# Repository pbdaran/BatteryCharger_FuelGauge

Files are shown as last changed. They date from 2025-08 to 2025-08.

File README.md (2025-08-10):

# Breakout Board: Battery Charger & Fuel Gauge — Design Story and Choices

Designing a compact, reliable battery management breakout board isn’t just about cramming chips together — it’s about understanding the trade-offs behind every component choice.  
Here’s the thinking behind the **Battery Charger & Fuel Gauge Breakout Board** and why I chose the ICs I did.

## 1. The Battery Charger: BQ24040 vs. TP4056

The **TP4056** has earned its fame in the maker world — it’s cheap, easy to use, and well supported. But it hides a quirk that can cause headaches in certain designs.

**The TP4056 quirk:**
- Pre-charge threshold: ~3.0 V
- Fixed pre-charge (trickle charge) current: **10 mA**
- If your battery is below 3 V and you have an **LDO** pulling ~10 mA from the charger output (to power 3.3 V logic, for instance), the TP4056 will happily supply that current to the LDO… **and zero to the battery**.
- Result? The battery never rises above 3 V, and the charger never switches to constant current mode. Stalemate.

**How the BQ24040 solves it:**
- **Lower pre-charge threshold**: ~2.5 V (battery starts charging earlier in its discharge)
- **Configurable pre-charge current**: e.g., 50 mA — plenty to both feed your LDO and still trickle energy into the cell.
- Additional perks:
  - Power path management: can supply load and charge battery simultaneously.
  - Status outputs for charge and fault indication.
  - Thermal regulation built in.

This means your system boots faster from a dead battery, and you don’t get stuck in a “never charging” deadlock.

## 2. The Fuel Gauge: BQ27621-G1 and the Calibration Dilemma

Battery fuel gauging is trickier than it looks. You can measure voltage, but it doesn’t tell the whole story about state of charge (SoC).

**Two main approaches:**
1. **Impedance Tracking** — Highly accurate, but requires painful calibration and “training” cycles to match the gauge to your specific cell.  
   Great for high-volume products, less great for quick prototypes or small-run boards.
2. **Voltage Correlation** — Uses cell voltage, temperature, and discharge patterns to estimate SoC. Less accurate over extreme conditions, but easy to set up.

The **BQ27621-G1** uses a **dynamic voltage correlation algorithm**:
- No complex calibration process.
- Good enough accuracy for most portable projects.
- Very low quiescent current — ideal for battery-powered devices.
- I²C interface for easy microcontroller integration.

For a breakout board aimed at prototyping and flexibility, avoiding impedance tracking’s long setup time is worth the small trade-off in accuracy.

## 3. Board Connections and Options

This board isn’t just two chips and some passives — it’s designed to be **flexible** in different setups.

**Key features:**
- **USB input** for charging.
- **Battery JST connector** for Li-Ion/Li-Po cells.
- **Load output** that stays powered even while charging (thanks to the BQ24040’s power path management).
- **I²C interface** (SDA, SCL) for reading fuel gauge data.
- **Configurable pre-charge current** via resistor selection.
- **Charge status pins** for LED indicators or MCU monitoring.

## 4. Why This Combo Works Well

The **BQ24040 + BQ27621-G1** pairing offers:
- Robust charging under low-voltage conditions.
- Accurate-enough battery state reporting without lengthy setup.
- Support for both charging and powering your project at the same time.
- Minimal parts count without sacrificing essential battery management features.

_Refer to the Design Document for the board configurations_

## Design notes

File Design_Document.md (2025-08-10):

# Hardware Design Document: BatteryCharger_FuelGauge_Breakout_Board

## 1. Overview

This breakout board provides battery charging and fuel gauging for single-cell Li-Ion batteries. It integrates the Texas Instruments BQ24040 battery charger and the BQ27621-G1 fuel gauge IC. The design supports USB-C input and configurable logic levels for host communication.

## 2. Major Components

### 2.1 Battery Charger IC (TI BQ24040)
- **Package:** WSON-10-1EP (2x2mm)
- **Functions:** Li-Ion single-cell battery charging, integrated power path management.
- **Key Pins:**
    - IN: Power input (VBUS from USB-C)
    - OUT: Charger output to battery and system
    - ISET/ISET2: Charge and input current setting (resistor configurable)
    - TS: Battery temperature sensing
    - PRETERM: Precharge current setting
    - ~CHG, ~PG: Charge and power-good status outputs
- **Thermal Pad (EPAD):** Must be connected to ground.

### 2.2 Fuel Gauge IC (TI BQ27621-G1)
- **Package:** DSBGA-9 (1.62x1.58mm)
- **Functions:** Battery fuel gauging via Impedance Track™.
- **Key Pins:**
    - BAT: Battery voltage sense
    - VDD: Power supply (1.8V internal, or external VDD)
    - SCL/SDA: I2C clock/data for host communication
    - GPOUT: Programmable output (status/interrupt)
    - BIN: Optional battery thermistor input (configurable via jumper)
    - NC: No connect

### 2.3 USB-C Input Connector
- **Type:** USB_C_Receptacle_USB2.0_16P
- **Pins:** VBUS, GND, CC1/CC2, SBU1/SBU2, D+/D- for USB 2.0 only.

### 2.4 Connectors
- **J1:** 5-pin host interface (VDDE, GPOUT, SCL, SDA, GND)
- **J2:** 3-pin battery connector (+BATT, BIN, GND)
- **J4:** 3-pin auxiliary connector

### 2.5 Passive Components
- **Resistors:** Current setting, pull-ups, configuration (e.g., 10k, 5.1k, 1.8M, 2k, 1k)
- **Capacitors:** Decoupling and filtering (e.g., 0.1uF, 1uF, 0.47uF)
- **TVS Diode:** USB port protection (SMBJ7.5CA)

### 2.6 Jumpers
- **JP1 (BIN select):** Selects battery temperature sensing mode (default disables BIN, option for thermistor).
- **JP2 (VDD select):** Selects power source for fuel gauge I/O (default external 3.3V, option for internal 1.8V).

## 3. Configuration Options

| Jumper | Default | Alternate | Description |
|---|---|---|---|
| JP1(1-2) | Pulled down through 10k; BIN disabled | JP1(2-3): Pulled up through 1.8M; battery pack must have thermistor | BIN configuration |
| JP2(1-2) | Connect external 3.3V on VDDE pin | JP2(2-3): Use 1.8V regulator output | VDD configuration for I2C interface |

## 4. Interfaces

### 4.1 Host Interface (J1)
| Pin | Signal | Description |
|-----|---|---|
| 1 | VDDE | Connect 3.3V (logic level) |
| 2 | GPOUT | Programmable output |
| 3 | SCL | I2C clock |
| 4 | SDA | I2C data |
| 5 | GND | Ground |

### 4.2 Battery Connector (J2)
| Pin | Signal | Description |
|-----|---|---|
| 1 | +BATT | Battery positive terminal |
| 2 | BIN | Battery NTC/thermistor |
| 3 | GND | Battery ground |

## 5. Power Domains

- **VBUS (USB):** Main input power for charging.
- **VDDE:** External I/O voltage (3.3V or 1.8V via JP2).
- **VDD:** Fuel gauge IC supply, from internal regulator or external VDDE.
- **GND:** System ground.

## 6. Notes & Recommendations

- By default, the BIN pin function is disabled. If your battery pack has an internal NTC, set JP1 to 2-3.
- By default, use external VDD of 3.3V on J1 pin 1. If your interface logic is 1.8V, set JP2 to 2-3 to use the fuel gauge's internal 1.8V regulator.
- TVS diode protects USB data lines.
- Mounting holes and fiducials are provided for PCB assembly.

## 7. Reference Designators

- **U1:** Fuel Gauge (BQ27621-G1)
- **U2:** Charger (BQ24040)
- **J1, J2, J3, J4:** Connectors
- **JP1, JP2:** Configuration jumpers
- **R1-R14, C1-C5, D1:** Passive components (refer to schematic for values and placement)
- **H1-H4:** Mounting holes
- **FID1-FID3:** Fiducials

## 8. Manufacturer & Part Numbers

| Ref | Component Type | MPN | Manufacturer | Value | Package/Footprint |
|-----|---|-----|---|---|---|
| U1  | Fuel Gauge IC | BQ27621YZFR-G1A | Texas Instruments | - | DSBGA-9 (1.62x1.58mm) |
| U2  | Battery Charger IC | BQ24040DSQT | Texas Instruments | - | WSON-10-1EP (2x2mm) |
| J1, J2, J4 | Pin Header Connector | 61300511121 (J1), G800W305018EU (J2/J4) | Würth Elektronik (J1), Amphenol ICC (J2/J4) | 1x5/1x3 | PinHeader_2.54mm_Vertical |
| J3 | USB-C Connector | USB4105-xx-A | GCT | USB 2.0, 16P | USB_C_Receptacle_GCT_USB4105-xx-A_16P_TopMnt_Horizontal |
| R1, R5, R8, R9 | Resistor | RMCF0603FT10K0 | Stackpole Electronics Inc | 10kΩ | R_0603_1608Metric |
| R2, R3, R13, R14 | Resistor | RMCF0603FT5K10 | YAGEO (R13/R14), Stackpole Electronics Inc | 5.1kΩ | R_0603_1608Metric |
| R4 | Resistor | RC0603FR-071M8L | YAGEO | 1.8MΩ | R_0603_1608Metric |
| R6 | Resistor | ERA-3AEB202V | Panasonic Electronic Components | 2kΩ | R_0603_1608Metric |
| R7 | Resistor | RMCF0603FT1K00 | Stackpole Electronics Inc | 1kΩ | R_0603_1608Metric |
| C1 | Capacitor | UMK107B7474KA-TR | Taiyo Yuden | 0.47µF | C_0603_1608Metric |
| C2, C4, C5 | Capacitor | CL10B105KO8NNNC | Samsung Electro-Mechanics | 1µF | C_0603_1608Metric |
| C3 | Capacitor | CC0603KRX7R7BB104 | YAGEO | 0.1µF | C_0603_1608Metric |
| D1 | TVS Diode | SMBJ7.5CA | Littelfuse Inc. | TVS | D_SMB_Handsoldering |

## 9. Schematic Source

File: `BatteryCharger_FuelGauge_Breakout_Board.kicad_sch`  
Version: v1  
Date: 2025-08-03

---

For further details, refer to the schematic and associated datasheets linked in the file.

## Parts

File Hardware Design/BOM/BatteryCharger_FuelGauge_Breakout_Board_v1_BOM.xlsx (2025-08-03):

S.No. | Reference Designator | Qty | Value | MPN | Manufacturer | Description
1 | U2 | 1 | BQ24040 | BQ24040DSQT | Texas Instruments | IC BATT CHG LI-ION 1CELL 10SON
2 | U1 | 1 | BQ27621-G1 | BQ27621YZFR-G1A | Texas Instruments | IC BATT FUEL GAUGE LIION 9DSBGA
3 | > R7, R10, R11 | 3 | 1k | RMCF0603FT1K00 | Stackpole Electronics Inc | Resistor, US symbol
4 | > R2, R3 | 2 | 5.1k | RMCF0603FT5K10 | Stackpole Electronics Inc | Resistor, US symbol
5 | > R13, R14 | 2 | 5.1k | RC0603FR-075K1L | YAGEO | Resistor, US symbol
6 | > R1, R5, R8, R9 | 4 | 10k | RMCF0603FT10K0 | Stackpole Electronics Inc | Resistor, US symbol
7 | R6 | 1 | 2k | ERA-3AEB202V | Panasonic Electronic Components | Resistor, US symbol
8 | R4 | 1 | 1.8M | RC0603FR-071M8L | YAGEO | Resistor, US symbol
9 | > J2, J4 | 2 | Conn_01x03_Pin | G800W305018EU | Amphenol ICC (Commercial Products) | Generic connector, single row, 01x03, script generated
10 | J1 | 1 | Conn_01x05_Pin | 61300511121 | Würth Elektronik | Generic connector, single row, 01x05, script generated
11 | > FID1-FID3, H1-H4, J3, JP1, JP2 | 10 | -- mixed values -- |  |  | -- mixed values --
12 | D1 | 1 | D_TVS | SMBJ7.5CA | Littlefuse Inc. | Bidirectional transient-voltage-suppression diode
13 | > C2, C4, C5 | 3 | 1u | CL10B105KO8NNNC | Samsung Electro-Mechanics | Unpolarized capacitor
14 | C3 | 1 | 0.1u | CC0603KRX7R7BB104 | YAGEO | Unpolarized capacitor
15 | C1 | 1 | 0.47u | UMK107B7474KA-TR | Taiyo Yuden | Unpolarized capacitor

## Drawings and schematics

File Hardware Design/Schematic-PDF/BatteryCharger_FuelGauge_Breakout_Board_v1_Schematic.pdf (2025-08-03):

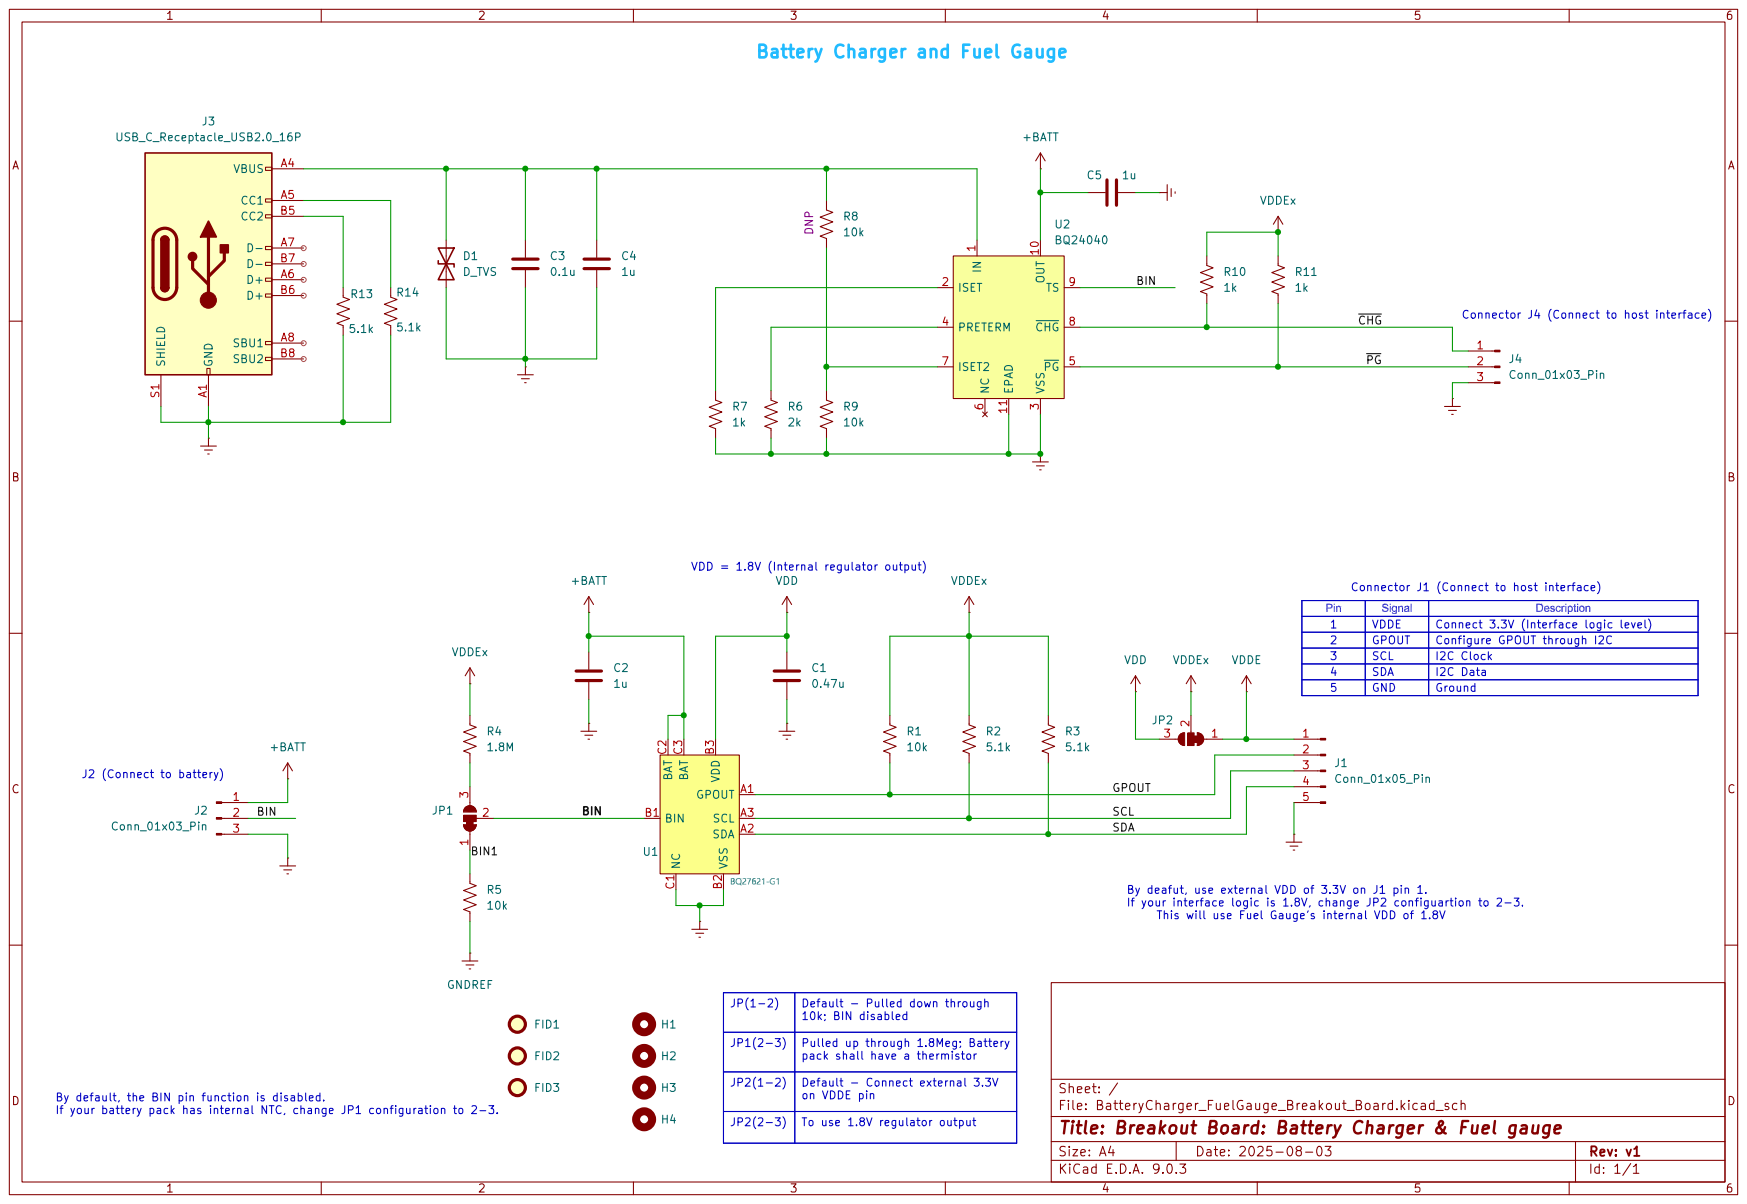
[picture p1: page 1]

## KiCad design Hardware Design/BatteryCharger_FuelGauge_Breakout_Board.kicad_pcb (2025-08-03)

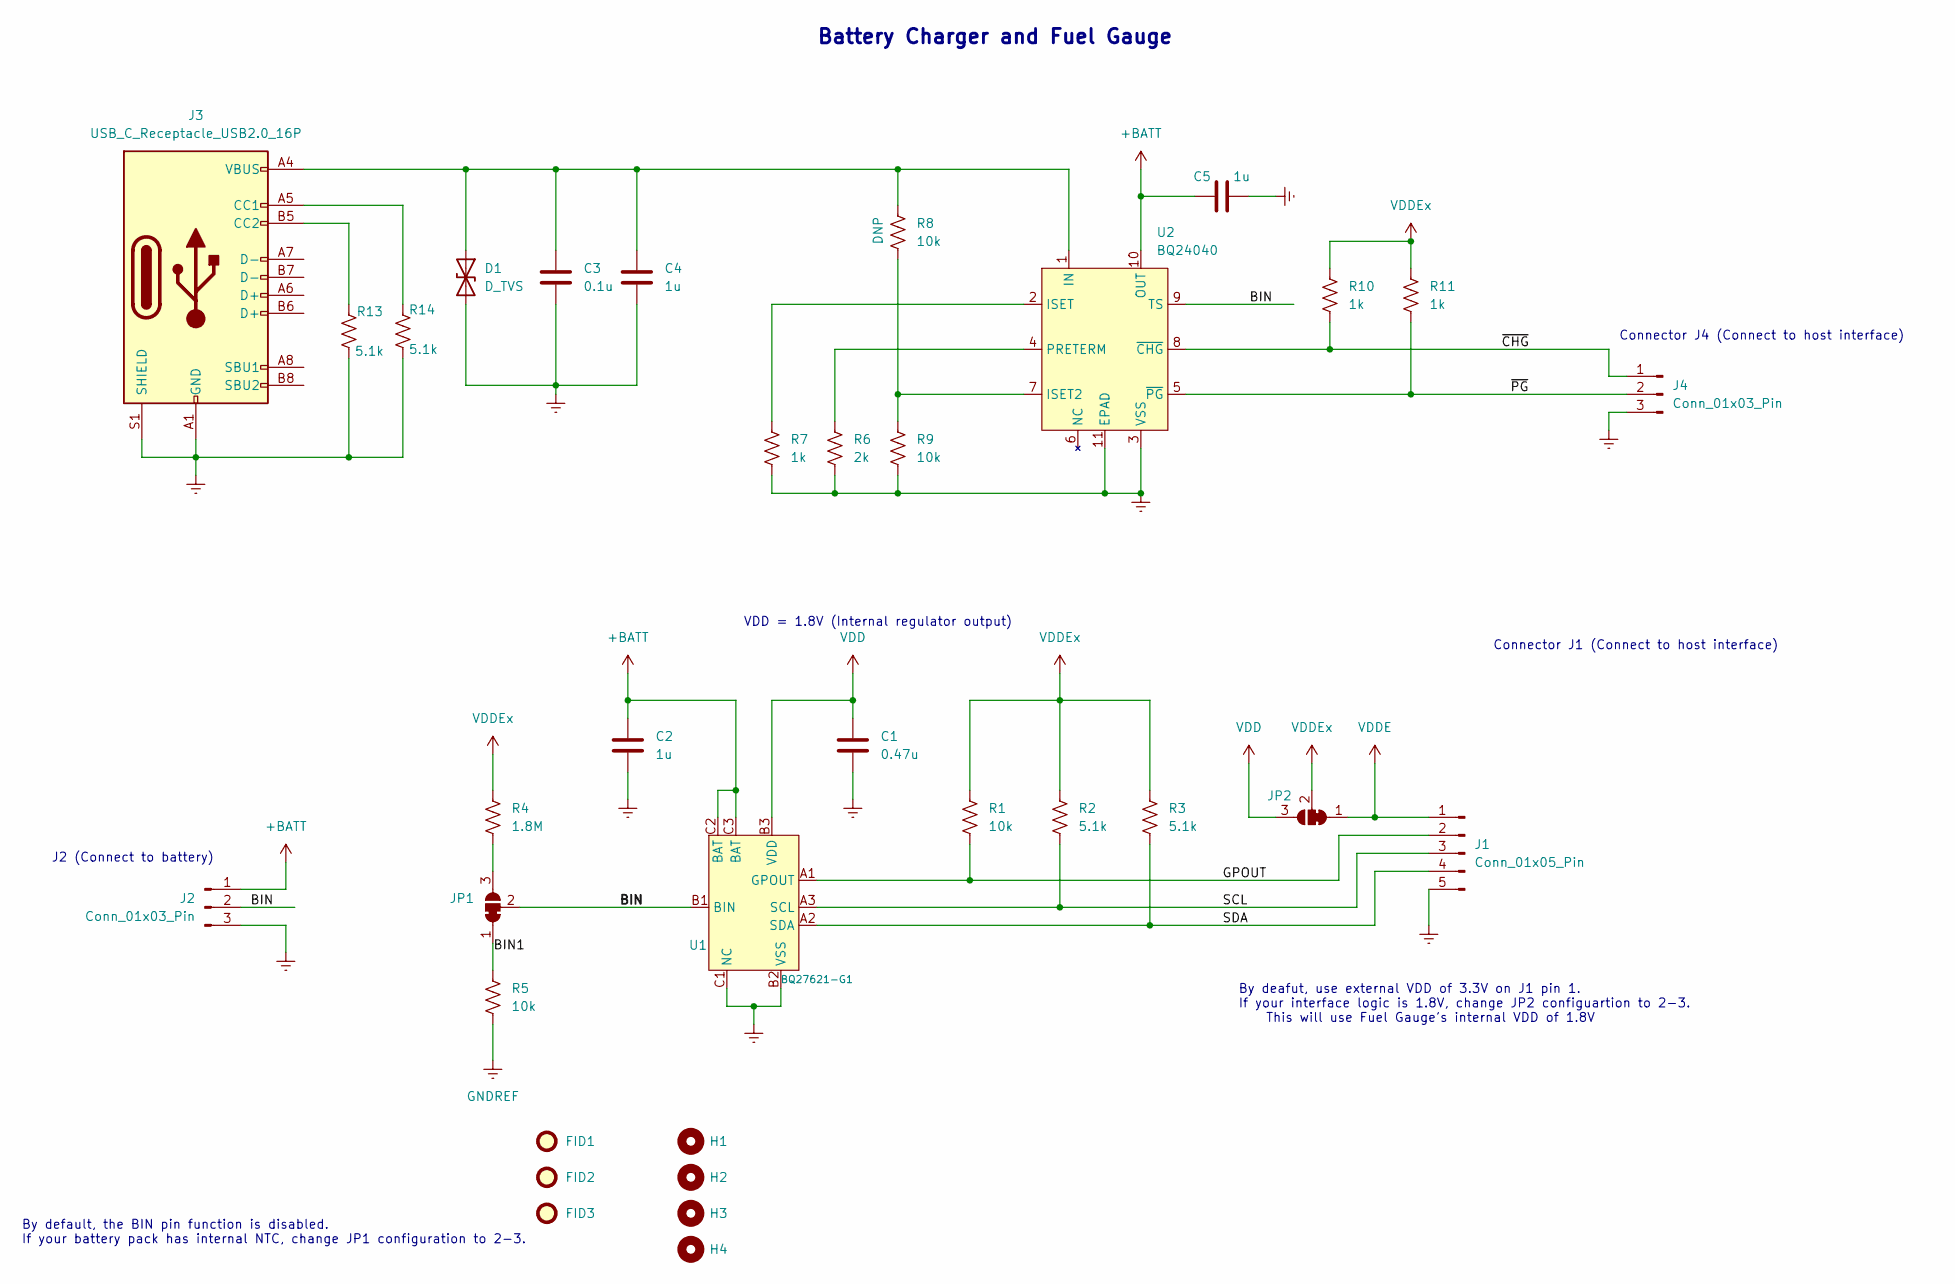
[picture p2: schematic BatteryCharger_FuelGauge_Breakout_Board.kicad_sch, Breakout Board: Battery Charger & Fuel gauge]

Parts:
C1: 0.47u; C_0603_1608Metric_Pad1.08x0.95mm_HandSolder; MPN UMK107B7474KA-TR
C2, C4, C5: 1u; C_0603_1608Metric_Pad1.08x0.95mm_HandSolder; MPN CL10B105KO8NNNC
C3: 0.1u; C_0603_1608Metric_Pad1.08x0.95mm_HandSolder; MPN CC0603KRX7R7BB104
D1: D_TVS; D_SMB_Handsoldering; MPN SMBJ7.5CA
FID1, FID2, FID3: Fiducial; Fiducial_0.5mm_Mask1mm
H1, H2, H3, H4: MountingHole; MountingHole_2.2mm_M2
J1: Conn_01x05_Pin; PinHeader_1x05_P2.54mm_Vertical; MPN 61300511121
J2, J4: Conn_01x03_Pin; PinHeader_1x03_P2.54mm_Vertical; MPN G800W305018EU
J3: USB_C_Receptacle_USB2.0_16P; USB_C_Receptacle_GCT_USB4105-xx-A_16P_TopMnt_Horizontal
JP1, JP2: SolderJumper_3_Bridged12; SolderJumper-3_P1.3mm_Bridged12_Pad1.0x1.5mm
R1, R5, R8, R9: 10k; R_0603_1608Metric_Pad0.98x0.95mm_HandSolder; MPN RMCF0603FT10K0
R2, R3: 5.1k; R_0603_1608Metric_Pad0.98x0.95mm_HandSolder; MPN RMCF0603FT5K10
R4: 1.8M; R_0603_1608Metric_Pad0.98x0.95mm_HandSolder; MPN RC0603FR-071M8L
R6: 2k; R_0603_1608Metric_Pad0.98x0.95mm_HandSolder; MPN ERA-3AEB202V
R7, R10, R11: 1k; R_0603_1608Metric_Pad0.98x0.95mm_HandSolder; MPN RMCF0603FT1K00
R13, R14: 5.1k; R_0603_1608Metric_Pad0.98x0.95mm_HandSolder; MPN RC0603FR-075K1L
U1: BQ27621-G1; Texas_DSBGA-9_1.62x1.58mm_Layout3x3_P0.5mm; MPN BQ27621YZFR-G1A
U2: BQ24040; WSON-10-1EP_2x2mm_P0.4mm_EP1.5x0.9mm; MPN BQ24040DSQT

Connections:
+BATT: C2.1, C5.1, J2.1, U1.C2 (BAT), U1.C3 (BAT), U2.10 (OUT)
/BIN: J2.2, JP1.2 (C), U1.B1 (BIN), U2.9 (TS)
/BIN1: JP1.1 (A), R5.1
/GPOUT: J1.2, R1.2, U1.A1 (GPOUT)
/SCL: J1.3, R2.2, U1.A3 (SCL)
/SDA: J1.4, R3.2, U1.A2 (SDA)
/~CHG: J4.1, R10.2, U2.8 (~CHG)
/~PG: J4.2, R11.2, U2.5 (~PG)
GNDREF: C1.2, C2.2, C3.2, C4.2, C5.2, D1.2 (A2), J1.5, J2.3, J3.A1 (GND), J3.A12 (GND), J3.B1 (GND), J3.B12 (GND), J3.S1 (SHIELD), J4.3, R5.2, R6.2, R7.2, R9.2, R13.2, R14.2, U1.B2 (VSS), U1.C1 (NC), U2.3 (VSS), U2.11 (EPAD)
unnamed: C3.1, C4.1, D1.1 (A1), J3.A4 (VBUS), J3.A9 (VBUS), J3.B4 (VBUS), J3.B9 (VBUS), R8.1, U2.1 (IN)
unnamed: J3.A5 (CC1), R14.1
unnamed: J3.B5 (CC2), R13.1
unnamed: JP1.3 (B), R4.2
unnamed: R8.2, R9.1, U2.7 (ISET2)
unnamed: R7.1, U2.2 (ISET)
unnamed: R6.1, U2.4 (PRETERM)
VDD: C1.1, JP2.3 (B), U1.B3 (VDD)
VDDE: J1.1, JP2.1 (A)
VDDEx: JP2.2 (C), R1.1, R2.1, R3.1, R4.1, R10.1, R11.1

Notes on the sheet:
By default, the BIN pin function is disabled. If your battery pack has internal NTC, change JP1 configuration to 2-3.
VDD = 1.8V (Internal regulator output)
Connector J4 (Connect to host interface)
Battery Charger and Fuel Gauge
J2 (Connect to battery)
Connector J1 (Connect to host interface)
By deafut, use external VDD of 3.3V on J1 pin 1. If your interface logic is 1.8V, change JP2 configuartion to 2-3. This will use Fuel Gauge's internal VDD of 1.8V

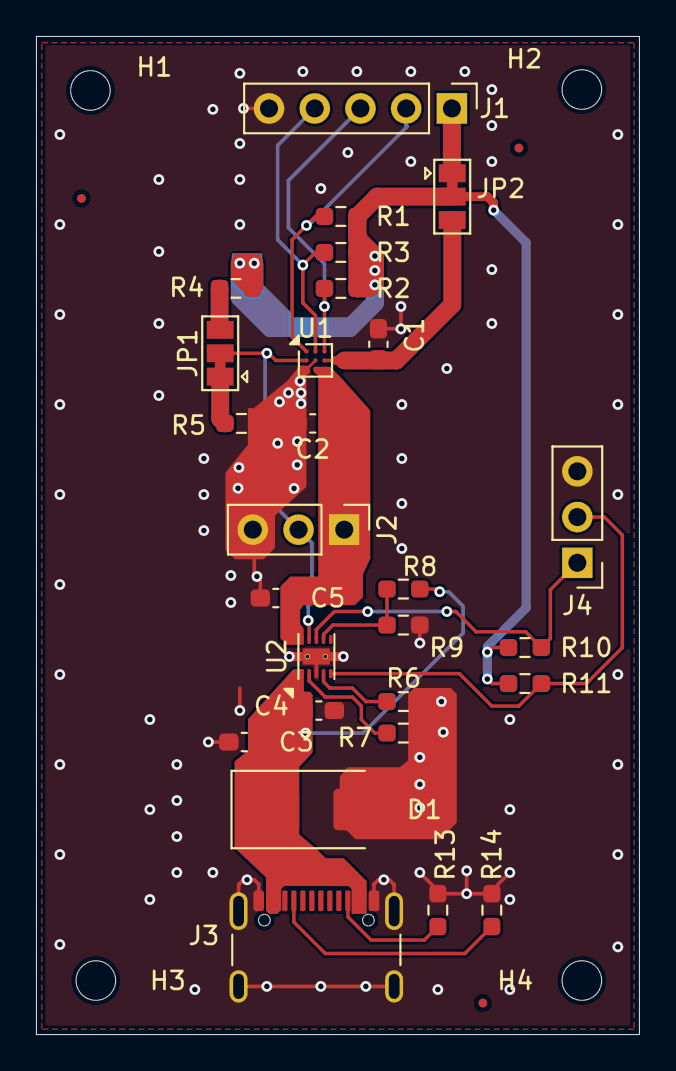
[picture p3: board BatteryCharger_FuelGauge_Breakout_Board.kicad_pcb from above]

Board: 2 copper layers, 33.5 x 55.5 mm, 34 parts (0 on the bottom side), 19 nets.
